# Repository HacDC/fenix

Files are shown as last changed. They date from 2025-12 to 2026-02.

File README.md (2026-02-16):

# Franken-Fenix





[HacDC's Spaceblimp VIII](https://wiki.hacdc.org/en/Projects/spaceblimp/Space-Blimp)

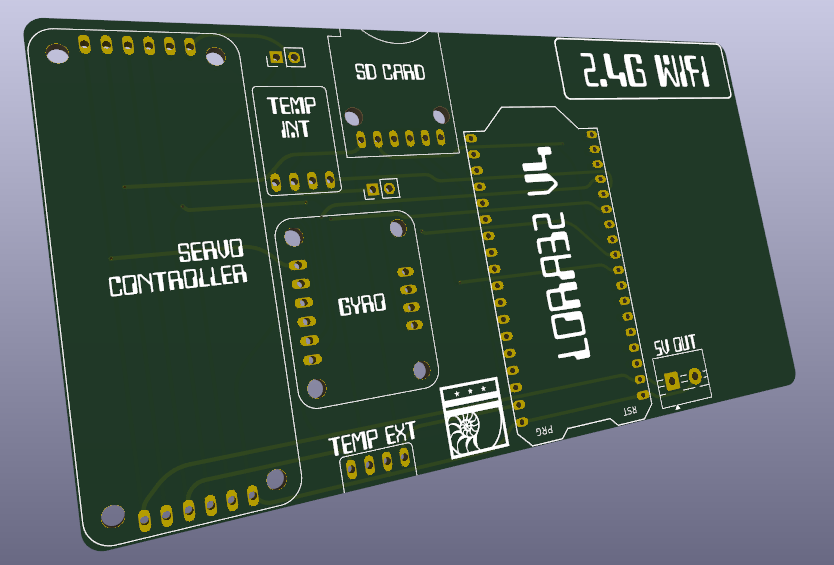
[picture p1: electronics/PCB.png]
Franken Fenix Prototype PCB render


# Supported Development Platforms

In theory it shouldn't really matter what operating system your computer
uses. This may or may not be the case in practice:

* Ubuntu: works

* MacOS: Doesn't work: arm issue

* Windows Subsystem for Linux: Operational (at least with Ubuntu noble)

* NixOS: Does not work (NixOS/nixpkgs#372653). Ivan is trying to find a
  workaround that we can use until the proper fix is merged
  (NixOS/nixpkgs#477552).

# Setup

1. If you haven't already done so, you must first install Nix. The official
   installation guide can be found here: https://nix.dev/install-nix

2. Any time you open a new terminal window, you will need to run
   `nix develop`.

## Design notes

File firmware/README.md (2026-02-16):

This crate produces two binaries:

* fenix: The firmware for the spaceblimp. Designed around the V4 LoRa32.

* fraublucher: The firmware for the ground station. Designed around the V3 LoRa32.

# Development Process

If you want to build and flash the spaceblimp firmware, use this command:

```shell
cargo run --bin fenix
```

The command for building and flashing the ground station is similar:

```shell
cargo run --bin fraublucher
```

If you want to build both without flashing either of them, then use this
command:

```shell
cargo build
```

## Troubleshooting

Sometimes a successful board flash requires wiping the device first. 
```shell
esptool --port /dev/$PORT erase-flash
```

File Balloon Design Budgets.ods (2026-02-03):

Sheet: mass_and_power
HacDC Space Blimp "Fenix"
Mass & Pwr Design Budgets | DRAFT/TEMPLATE
Item | Mass (gm) | Power (Peak) | Power (Avg) | Min Temp (degC)
Structure |  | 0 | 0
Harness
Mounting Frame & Hardware
Warm Box
Main Board
PCB
CPU Module
GPS Module
uSD Module
Servo Controller
Gyro/Compass/Temp Sensor
Host Platform
Battery
Servo(s)
GPS & command/ctrl antennas
Heaters
Balloon Valve
Payloads
Film Camera
AirTag
Meshtastic Node
Payload Antenna(s)

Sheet: RF_link
HacDC Space Blimp "Fenix" |  | RF Link Budget
Parameter | Value |  | Alternate units |  |  |  |  | Notes
altitude | 35 | km | 114829 | ft | 21.7 | mi |  | est max burst altitude
angle from vertical | 27.5 | deg |  |  |  |  |  | 55 deg is -3dB beamwidth of antenna
ground dist | 18.2 | km | 59776 | ft | 11.3 | mi
total slant distance | 39.5 | km | 129457 | ft | 24.5 | mi
freq. | 907 | MHz
free space path loss | 123.5 | dB |  |  |  |  |  | (same as http://www.everythingrf.com/rf-calculators/free-space-path-loss-calculator)
TX power | 27.0 | dBm |  |  |  |  |  | from datasheet, 28 +/-1 dBm
TX cable loss | -3.0 | dB |  |  |  |  |  | est
TX antenna matching loss | -3.0 | dB |  |  |  |  |  | est
TX antenna gain | 3.7 | dB |  |  |  |  |  | 7.7 max at 0 deg for perfect antenna, -1 for construction
FSPL (from above) | -123.5 | dB
polarization match loss | -3.0 | dB |  |  |  |  |  | est for a) CP to linear or b) linear/linear at 60 deg skew
RX antenna gain | 0.0 | dB |  |  |  |  |  | assume isotropic for now
RX cable loss | -3.0 | dB |  |  |  |  |  | est
RX matching loss | -3.0 | dB |  |  |  |  |  | est
received power: | -107.8 | dBm
RX sensitivity | -137.0 | RX dBm |  |  |  |  |  | per datasheet
RX margin | 29.2 | dB |  |  |  |  |  | needs to be >>0 dB to have chance of RX
 |  |  |  |  | summary of a few cases
 |  |  |  |  | angle (deg) | gnd dist (km) | RX margin (dB)
 |  |  |  |  | 0 | 0 | 33.2
 |  |  |  |  | 27.5 | 18.2 | 29.2
 |  |  |  |  | 48.0 | 38.9 | 19.7
 |  |  |  |  | 60.0 | 68.7 | 6.4

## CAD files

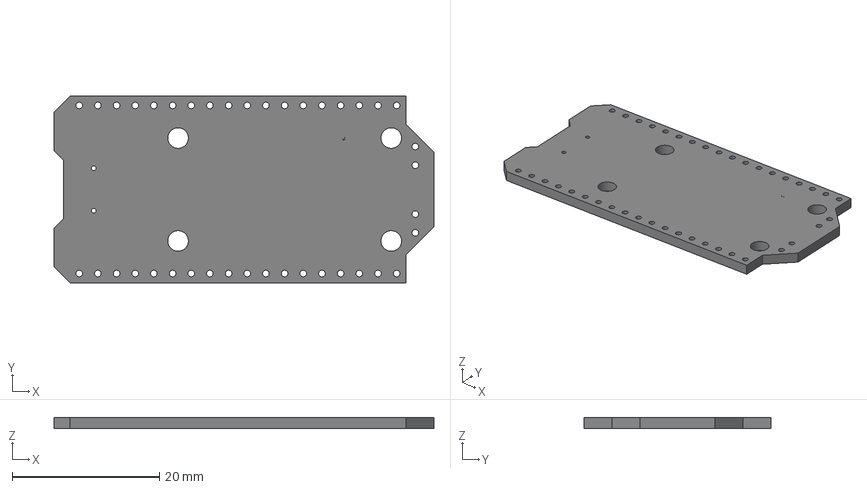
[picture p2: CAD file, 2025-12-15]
electronics/models/Lora32_V4.step
51.7 x 25.4 x 1.56 mm

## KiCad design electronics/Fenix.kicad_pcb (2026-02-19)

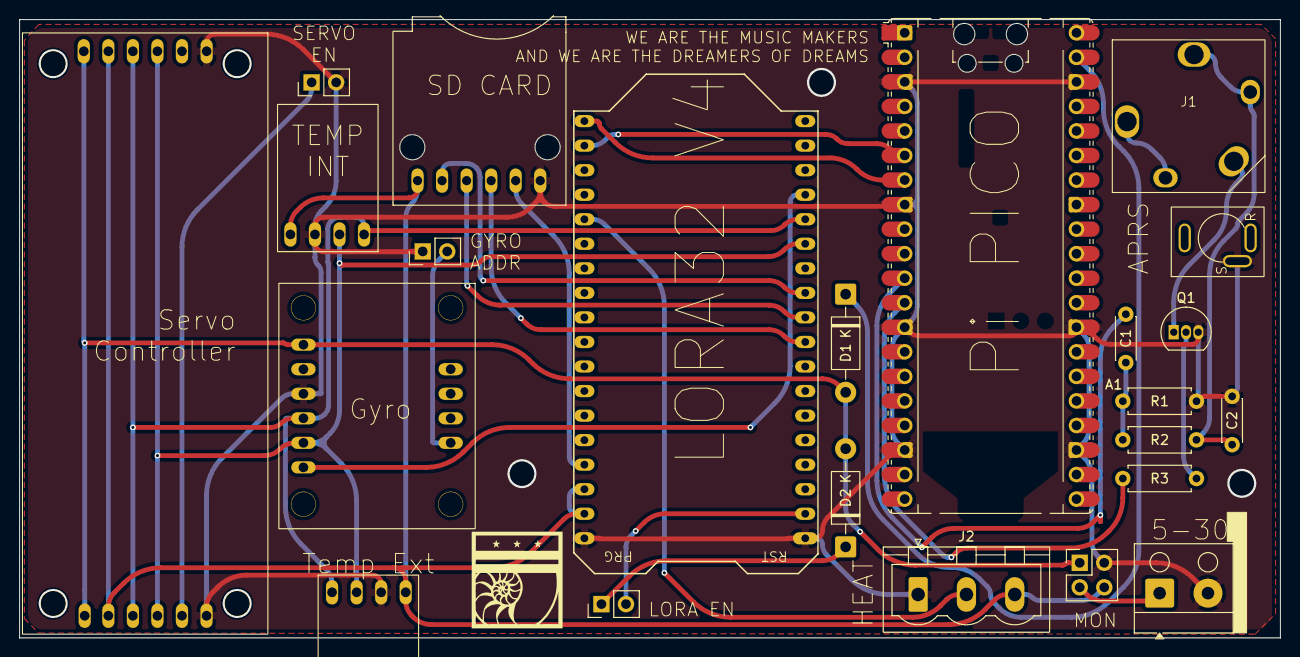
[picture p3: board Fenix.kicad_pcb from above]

Board: 2 copper layers, 130.5 x 64.0 mm, 23 parts (0 on the bottom side), 25 nets.

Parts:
A1: RaspberryPi_Pico; RaspberryPi_Pico_Common_Unspecified
C1: 100nF; C_Disc_D4.3mm_W1.9mm_P5.00mm
C2: 4.7nF; C_Disc_D4.3mm_W1.9mm_P5.00mm
D1, D2: 1N5817; D_DO-41_SOD81_P10.16mm_Horizontal
Gyro1: Adafruit_BNO055
J1: Radio 3.5mm; TRS_3.5mm
J2: Relay_Control; PhoenixContact_MSTBVA_2,5_3-G_1x03_P5.00mm_Vertical
J3: Radio 2.5mm; TRS_2.5mm
J3_ADR1, J4_LORA_PWR1, J4_SRV_EN1: Conn_01x02_Pin; PinHeader_1x02_P2.54mm_Vertical
J4: PWR_MON; PinHeader_2x02_P2.54mm_Vertical
J5: PWR_IN; Altech_AK100_1x02_P5.00mm
LoRa32_V1: LORA32_V4
Q1: BC548; TO-92_Inline
R1, R2: 4k7; R_Axial_DIN0207_L6.3mm_D2.5mm_P7.62mm_Horizontal
R3: 1k; R_Axial_DIN0207_L6.3mm_D2.5mm_P7.62mm_Horizontal
Servo_Controller1: Adafruit_PCA9685
TEMP_EXT1: GY-SHT31-D
TEMP_INT1: GY-SHT31-D
uSD1: Generic_uSD

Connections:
+3V3: J2.3, J4.4, LoRa32_V1.34 (3v3), LoRa32_V1.35 (3V3), Servo_Controller1.5 (VCC), Servo_Controller1.8 (VCC), TEMP_EXT1.1 (VIN), TEMP_INT1.1 (VIN), uSD1.1 (3V3)
+5V: D1.2 (A), D2.2 (A), Gyro1.1 (VIN), J4.1, Servo_Controller1.6 (V+), Servo_Controller1.7 (V+)
/APRS_3.5_Sleeve: J1.S, Q1.1 (C)
/APRS_RX: A1.6 (GPIO4), LoRa32_V1.20 (G06)
/APRS_TX: A1.7 (GPIO5), LoRa32_V1.19 (G07)
/GYRO_RST: Gyro1.6 (RST), LoRa32_V1.15 (G26)
/I2C_CLK: Gyro1.5 (SCL), LoRa32_V1.13 (G47), Servo_Controller1.3 (SCL), Servo_Controller1.10 (SCL), TEMP_EXT1.3 (SCL), TEMP_INT1.3 (SCL)
/I2C_DATA: Gyro1.4 (SDA), LoRa32_V1.14 (G48), Servo_Controller1.4 (SDA), Servo_Controller1.9 (SDA), TEMP_EXT1.4 (SDA), TEMP_INT1.4 (SDA)
/RELAY_EN: J2.2, LoRa32_V1.23 (G03)
/SPI_CLK: LoRa32_V1.09 (G36), uSD1.4 (CLK)
/SPI_CS_SD: LoRa32_V1.11 (G34), uSD1.2 (CS)
/SPI_PICO: LoRa32_V1.10 (G35), uSD1.3 (PICO)
/SPI_POCI: LoRa32_V1.33 (G37), uSD1.5 (POCI)
GND: A1.3 (GND), A1.8 (GND), A1.13 (GND), A1.18 (GND), A1.23 (GND), A1.28 (GND), A1.38 (GND), C2.2, Gyro1.3 (GND), J2.1, J3.S, J3_ADR1.1, J4.2, J4_SRV_EN1.2, J5.2, LoRa32_V1.01 (GND), LoRa32_V1.36 (GND), Q1.3 (E), R1.2, Servo_Controller1.1 (GND), Servo_Controller1.12 (GND), TEMP_EXT1.2 (GND), TEMP_INT1.2 (GND), uSD1.6 (GND)
unnamed: A1.11 (GPIO8), C1.2
unnamed: A1.12 (GPIO9), R3.2
unnamed: A1.39 (VSYS), D1.1 (K)
unnamed: C1.1, R1.1, R2.2
unnamed: C2.1, J1.R, R2.1
unnamed: D2.1 (K), J4_LORA_PWR1.1
unnamed: Gyro1.7 (ADR), J3_ADR1.2
unnamed: J4.3, J5.1
unnamed: J4_LORA_PWR1.2, LoRa32_V1.02 (5V)
unnamed: J4_SRV_EN1.1, Servo_Controller1.11 (OE)
unnamed: Q1.2 (B), R3.1

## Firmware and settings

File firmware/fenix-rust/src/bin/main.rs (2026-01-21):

#![no_std]
#![no_main]
#![deny(
    clippy::mem_forget,
    reason = "mem::forget is generally not safe to do with esp_hal types, especially those \
    holding buffers for the duration of a data transfer."
)]
#![deny(clippy::large_stack_frames)]

use embassy_executor::Spawner;
use embassy_time::{
    Delay,
    Duration,
    Timer
};
use embassy_sync::{
    mutex::Mutex,
    blocking_mutex::raw::CriticalSectionRawMutex
};
use embassy_embedded_hal::shared_bus::asynch::spi::SpiDevice;
use log::info;
use esp_hal::{
    clock::CpuClock,
    timer::timg::TimerGroup,
    gpio::{
        OutputConfig,
        InputConfig,
        Input,
        Output,
        Level
    },
    spi::{
        Mode,
        master::{
            Config,
            Spi
        },
    },
    time::Rate,
};
use lora_phy::{
    sx126x,
    LoRa,
    iv
};

use lora_config;

#[panic_handler]
fn panic(_: &core::panic::PanicInfo) -> ! {
    loop {}
}

extern crate alloc;

// This creates a default app-descriptor required by the esp-idf bootloader.
// For more information see: <https://docs.espressif.com/projects/esp-idf/en/stable/esp32/api-reference/system/app_image_format.html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>
esp_bootloader_esp_idf::esp_app_desc!();

static SPI_BUS: static_cell::StaticCell<Mutex<CriticalSectionRawMutex, Spi<'static, esp_hal::Async>>> =
    static_cell::StaticCell::new();

#[allow(
    clippy::large_stack_frames,
    reason = "it's not unusual to allocate larger buffers etc. in main"
)]
#[esp_rtos::main]
async fn main(spawner: Spawner) -> ! {
    // generator version: 1.2.0

    esp_println::logger::init_logger_from_env();

    let config = esp_hal::Config::default().with_cpu_clock(CpuClock::max());
    let peripherals = esp_hal::init(config);

    esp_alloc::heap_allocator!(#[esp_hal::ram(reclaimed)] size: 73744);

    let timg0 = TimerGroup::new(peripherals.TIMG0);
    esp_rtos::start(timg0.timer0);

    info!("Embassy initialized!");

    let radio_init = esp_radio::init().expect("Failed to initialize Wi-Fi/BLE controller");
    let (mut _wifi_controller, _interfaces) =
        esp_radio::wifi::new(&radio_init, peripherals.WIFI, Default::default())
            .expect("Failed to initialize Wi-Fi controller");

    // Initialize LoRa radio
    let nss = Output::new(peripherals.GPIO8, Level::High, OutputConfig::default());
    let sclk = peripherals.GPIO9;
    let pico = peripherals.GPIO10;
    let poci = peripherals.GPIO11;
    let rst = Output::new(peripherals.GPIO12, Level::Low, OutputConfig::default());
    let dio1 = Input::new(peripherals.GPIO14, InputConfig::default());
    let busy = Input::new(peripherals.GPIO13, InputConfig::default());
    let spi = Spi::new(
        peripherals.SPI2,
        Config::default()
            .with_frequency(Rate::from_khz(100))
            .with_mode(Mode::_0),
    )
    .unwrap()
    .with_sck(sclk)
    .with_mosi(pico)
    .with_miso(poci)
    .into_async();

    // Initialize Static SPI Bus
    let spi_bus = SPI_BUS.init(Mutex::new(spi));
    let spi_device = SpiDevice::new(spi_bus, nss);

    // Initialize LoRa Radio
    let interface_variant = iv::GenericSx126xInterfaceVariant::new(rst, dio1, busy, None, None).unwrap();
    let mut lora = LoRa::new(sx126x::Sx126x::new(spi_device, interface_variant, lora_config::RADIO_CONFIG), false, Delay)
        .await
        .unwrap();
    let mut rx_buffer = [0u8; lora_config::PACKET_CONFIG.length as usize];
    let modulation_config = {
        match lora.create_modulation_params(
            lora_config::MODULATION_CONFIG.spreading_factor,
            lora_config::MODULATION_CONFIG.bandwidth,
            lora_config::MODULATION_CONFIG.coding_rate,
            lora_config::FREQUENCY,
        ) {
            Ok(config) => config,
            Err(e) => {
                panic!("Failed to create modulation params: {:?}", e);
            }
        }
    };
    let mut tx_packet_config = {
        match lora.create_tx_packet_params(
            lora_config::PACKET_CONFIG.preamble,
            lora_config::PACKET_CONFIG.implicit_header,
            lora_config::PACKET_CONFIG.crc,
            lora_config::PACKET_CONFIG.invert_iq,
            &modulation_config
        ) {
            Ok(config) => config,
            Err(e) => {
                panic!("Failed to create tx packet params: {:?}", e);
            }
        }
    };
    // let tx_buffer = b"dasdjjdjksjdfhs";

    // TODO: Spawn some tasks
    let _ = spawner;

    loop {
        let message = b"Be gay, kill  nazis!";
        rx_buffer[..message.len()].copy_from_slice(message);
        match lora.prepare_for_tx(
            &modulation_config,
            &mut tx_packet_config,
            lora_config::LORA_POWER,
            &rx_buffer
        ).await {
            Ok(_) => {
                info!("LoRa radio initialized for TX!");
            }
            Err(e) => {
                panic!("Failed to prepare LoRa radio for TX: {:?}", e);
            }
        }
        match lora.tx().await {
            Ok(_) => {
                info!("LoRa TX successful!");
            }
            Err(e) => {
                panic!("LoRa TX failed: {:?}", e);
            }
        }
        match lora.sleep(true).await {
            Ok(_) => {
                info!("LoRa radio put to sleep!");
            }
            Err(e) => {
                panic!("Failed to put LoRa radio to sleep: {:?}", e);
            }
        }
        Timer::after(Duration::from_secs(5)).await;
    }

    // for inspiration have a look at the examples at https://github.com/esp-rs/esp-hal/tree/esp-hal-v1.0.0/examples
}

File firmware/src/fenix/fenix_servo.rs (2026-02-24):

// [This controller](https://cdn-shop.adafruit.com/datasheets/PCA9685.pdf) is on the I2C bus and can control up to 16 servos.

// The address is controlled by the daughterboard's solder jumpers, and defaults to `0x20` if left open. This is subject to change.

use crate::fenix::fenix_sd::{
    FenixDirectory,
    FenixFile,
};
use embedded_hal::i2c::I2c;

pub struct Servo<'a> {
    // TODO: this is way gross; especially if/when we need to create other
    // persistent variables. Create a separate KVS module?
    is_popped: bool,
    is_popped_file: FenixFile<'a>,
}

impl<'a> Servo<'a> {
    pub fn new(dir: &'a FenixDirectory, fname: &str, _i2c: &mut impl I2c) -> Self {
        // TODO: document the binary structure of this file?
        // Actually: instead of storing data in the file, we could just create the file when we pop?
        let is_popped_file = dir
            .open_file_in_dir(fname, embedded_sdmmc::Mode::ReadWriteCreateOrAppend)
            .unwrap();

        let mut bytes: [u8; 1] = [0];

        // TODO: this unwrap_or is bad? The correct solution is to check if the file exists before we open it?
        let num_bytes = is_popped_file.read(&mut bytes).unwrap_or(1);
        assert!(num_bytes == 1);

        let byte = bytes[0];
        let is_popped: bool = byte != 0;

        // TODO: don't assume that we haven't popped yet?
        Servo {
            is_popped,
            is_popped_file,
        }
    }

    pub fn is_popped(&self, _i2c: &mut impl I2c) -> bool {
        self.is_popped
    }

    pub fn pop(&mut self, _i2c: &mut impl I2c) {
        self.is_popped = true;
        let bytes: [u8; 1] = [1];
        self.is_popped_file.write(&bytes).unwrap();
        todo!();
    }

    pub fn take_picture1(&mut self, _i2c: &mut impl I2c) {
        todo!();
    }

    pub fn take_picture2(&mut self, _i2c: &mut impl I2c) {
        todo!();
    }
}

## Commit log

2025-11-30 Core Parts
    [Fenix.kicad_pcb, Fenix.kicad_sch]
2025-12-01 Completed parts library
    [Fenix.kicad_pcb, Fenix.kicad_sch]
2025-12-12 Added ToDos in schematic
    [Fenix.kicad_sch]
2025-12-15 Added uSD + Power connector
    [Fenix.kicad_pcb, Fenix.kicad_sch]
2025-12-15 Add 3dModel of Lora and remove silkscreen heltec
    [Lora32_V4.step]
2026-01-17 Create firmware instructions
    [Fenix.kicad_pcb, Fenix.kicad_sch, Lora32_V4.step]
2026-01-18 Generate ground-station project
2026-01-18 Regenerate ground-station project to comply with ASCII requirements
2026-01-19 Implement LoRa for ground station
2026-01-19 Cleanup KiCad leftovers
2026-01-19 Update Symbol/Footprint link & Remove GPS board
    [Fenix.kicad_pcb, Fenix.kicad_sch]
2026-01-19 Organize nets/symbols
    [Fenix.kicad_pcb, Fenix.kicad_sch]
2026-01-23 Hardware Night: Finish schematic and PCB routing for known parts
    [Fenix.kicad_pcb, Fenix.kicad_sch]
2026-01-23 Add PCB Render
2026-02-03 Switch to nix-based development environment
2026-02-03 design budget drafts
    [Balloon Design Budgets.ods, Balloon Design Budgets.xlsx]
2026-02-05 Update ecan, cleanup
    [Fenix.kicad_sch]
2026-02-06 Add prototype Github Action for building firmware
2026-02-07 I2C Scanner tool
2026-02-07 Add I2C bus
2026-02-10 A different failed attempt
    [fenix_sd.rs]
2026-02-10 Fix warnings about unused variables
    [fenix.rs, fenix_lora.rs]
2026-02-16 Start implementing servo support
2026-02-16 Fix merge with Ivan's servo work
    [fenix.rs]
2026-02-18 APRS Schematic
    [Fenix.kicad_sch]
2026-02-18 APRS Footprints
    [Fenix.kicad_sch]
2026-02-19 Some PCB layout, will need to redo 3.5mm jack footprint
    [Fenix.kicad_pcb]
2026-02-19 Pre-Routing Board Layout
    [Fenix.kicad_pcb, Fenix.kicad_sch]
2026-02-19 Completed PCB Design
    [Fenix.kicad_pcb]
2026-02-24 Create a file for storing servo state
2026-03-27 Fix fenix crash thing
    [fenix.rs]
